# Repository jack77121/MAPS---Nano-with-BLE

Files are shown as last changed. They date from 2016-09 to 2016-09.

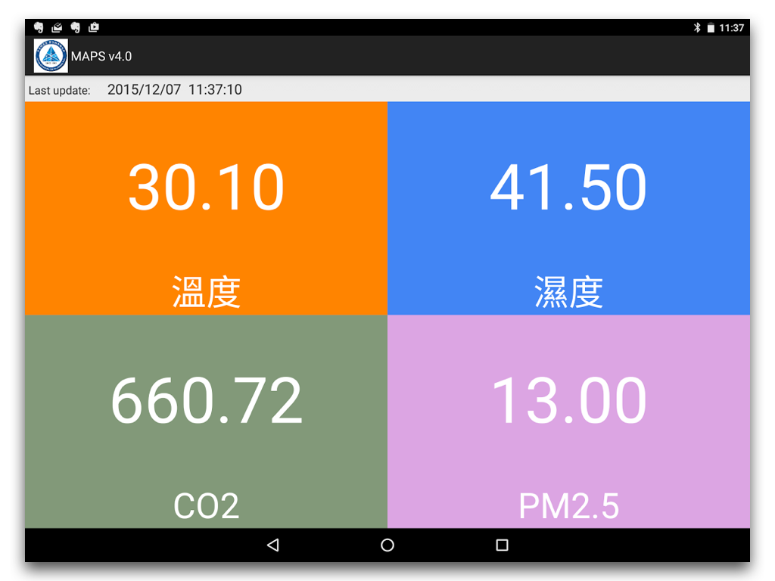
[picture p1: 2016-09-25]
app_figure.png

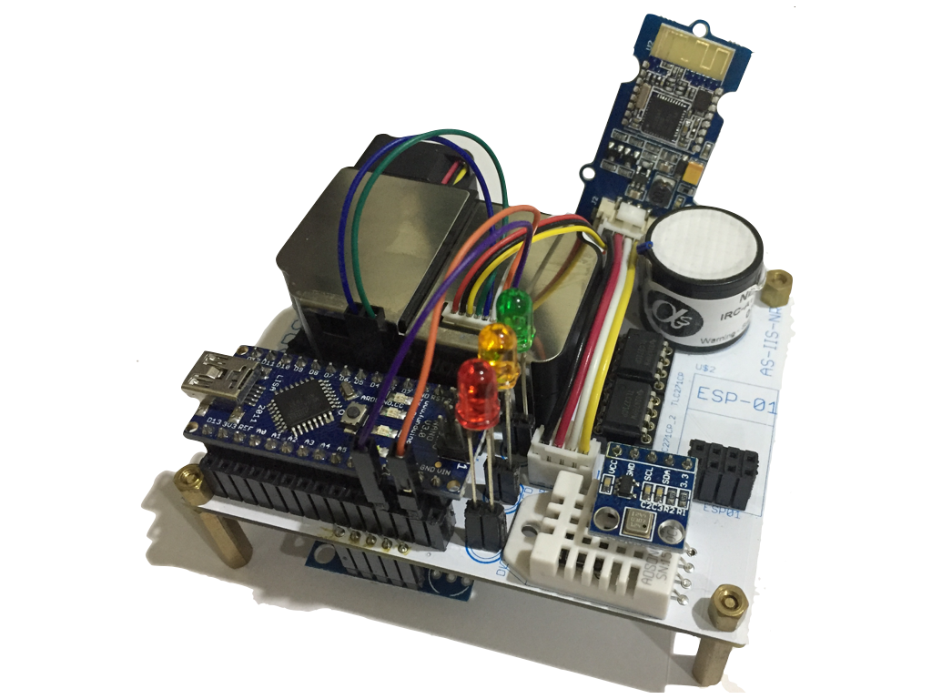
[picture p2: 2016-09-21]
MAPS_BLE_appearance.png

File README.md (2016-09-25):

# MAPS-Arduino Nano
![Image of PCB layout]
(https://github.com/jack77121/MAPS---Nano-with-BLE/blob/master/MAPS_BLE_appearance.png)

## Story
**M**icro **A**ir **P**ollution **S**ensing - MAPS

Air pollution is a hot topic in recent years, especially - **Particulate Matter**. Traditional sensing method, we can only depend on professional sensors/devices, with large volume, heave weight and insanity price.
Thanks to the technology, now we could build our own air pollution sensing station, with micro volume, light weight and the price is affordable :). With MAPS, you can sense air pollution any where, any time by yourself, you can also give it a battery module to increase its mobility!

For more air pollution sensing project, you can visit [LASS facebook](https://www.facebook.com/groups/1607718702812067/) and [LASS github](https://github.com/LinkItONEDevGroup/LASS), we are makers who sense anything in our environment!

## Hardware & Sensors
Module      |	Description
------------|--------------
Arduino Nano|Mainboard
RTC         |time sync
BLE         |pair with smart phone
G3 (pms3003)|Particalute matter (PM)
DHT22       |Temperature & humidity
BMP180      |Ambient pressure
IRC-A1      |CO<sub>2</sub>

## PCB layout & dimensions
![Image of pcb layout]
(https://github.com/jack77121/MAPS---Nano-with-BLE/blob/master/PCB_layout.png)

(unit: mm)

## Installation
1. Upload *MAPS_BLE.ino* to your nano.
2. Compile and install *MAPS_ble* to android phone.
3. Choose to pair the MAPS BLE module from app.
4. You are ready to see the sensors data on you phone.

![Image of app after pairing]
(https://github.com/jack77121/MAPS---Nano-with-BLE/blob/master/app_figure.png)

## Notes
* I use 3 LEDs to show the CO<sub>2</sub> and PM level, whether its safe (green: PM<sub>2.5</sub> <= 32 and CO<sub>2</sub> <= 1000), warning (orange: 32 < PM<sub>2.5</sub> <= 53) and danger (red: PM<sub>2.5</sub> >53 or CO<sub>2</sub> > 1000)
* BLE module use grove universal sockets, can easily replace with your favorite module (maybe a data logger instead), just beware that the socket is connect to **5v power**. 
* ESP-01 socket is preserve for esp8266 module extension, it's fine to leave it if you don't need it.

## Reviews
1. IRC-A1 is a good sensor for CO<sub>2</sub> sensing, but with great power, you also need great skill to use it. You need to add operational amplifier (OPA) in your circuit, infact, most of my circuit and components are for the IRC-A1, include TLC271cp (OPA), IRF520 (MOSFET) and several resistor & capacitor. You also need to calibrate it, with ZERO gas (0 ppm CO<sub>2</sub>) and fix-concentration target gas (for me, 1000 ppm CO<sub>2</sub>).
I think the better circuit should use an external power with low-dropout (LDO) regulator as its power source, and use a crystal oscillator to trigger it (like it mention in its spec, but in this project, I use arduino PWM library to simulate the duty cycle it needs, maybe that's why I cannnot get the best result) .
2. The polygon of GND should not be that large, because it transfers the heat, and it will affect the DHT22 accuracy.

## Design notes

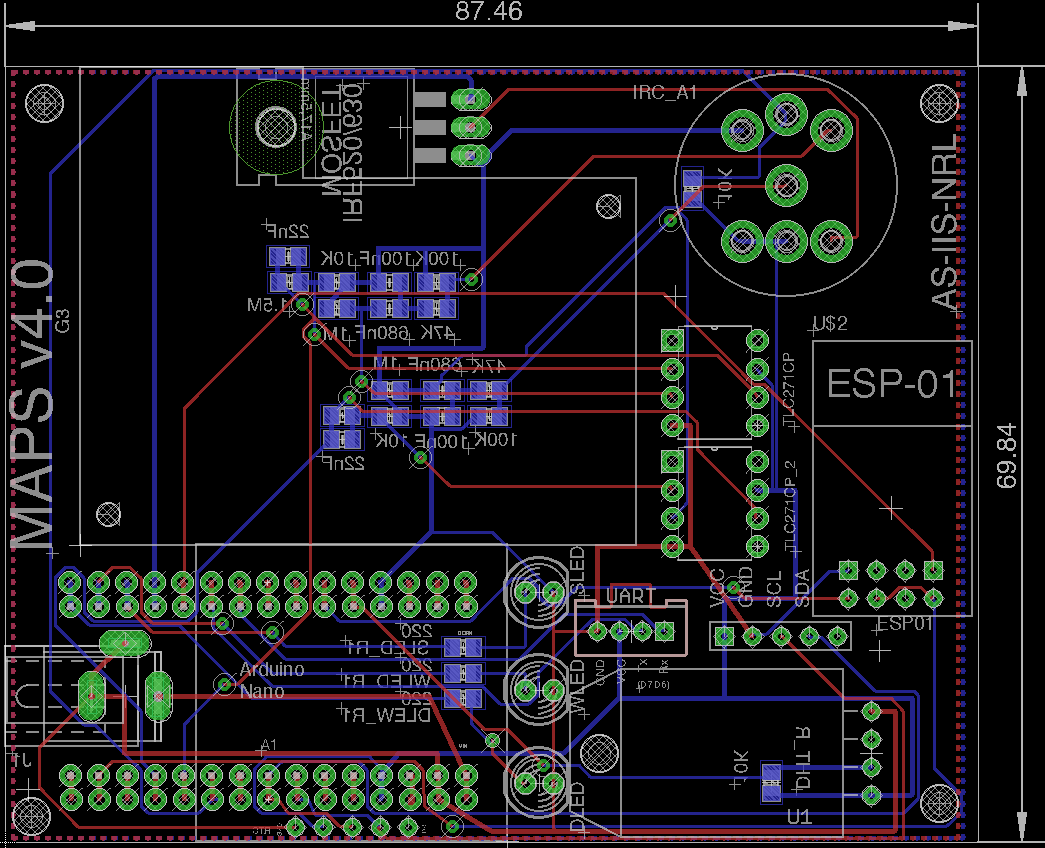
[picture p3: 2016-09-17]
PCB_layout.png

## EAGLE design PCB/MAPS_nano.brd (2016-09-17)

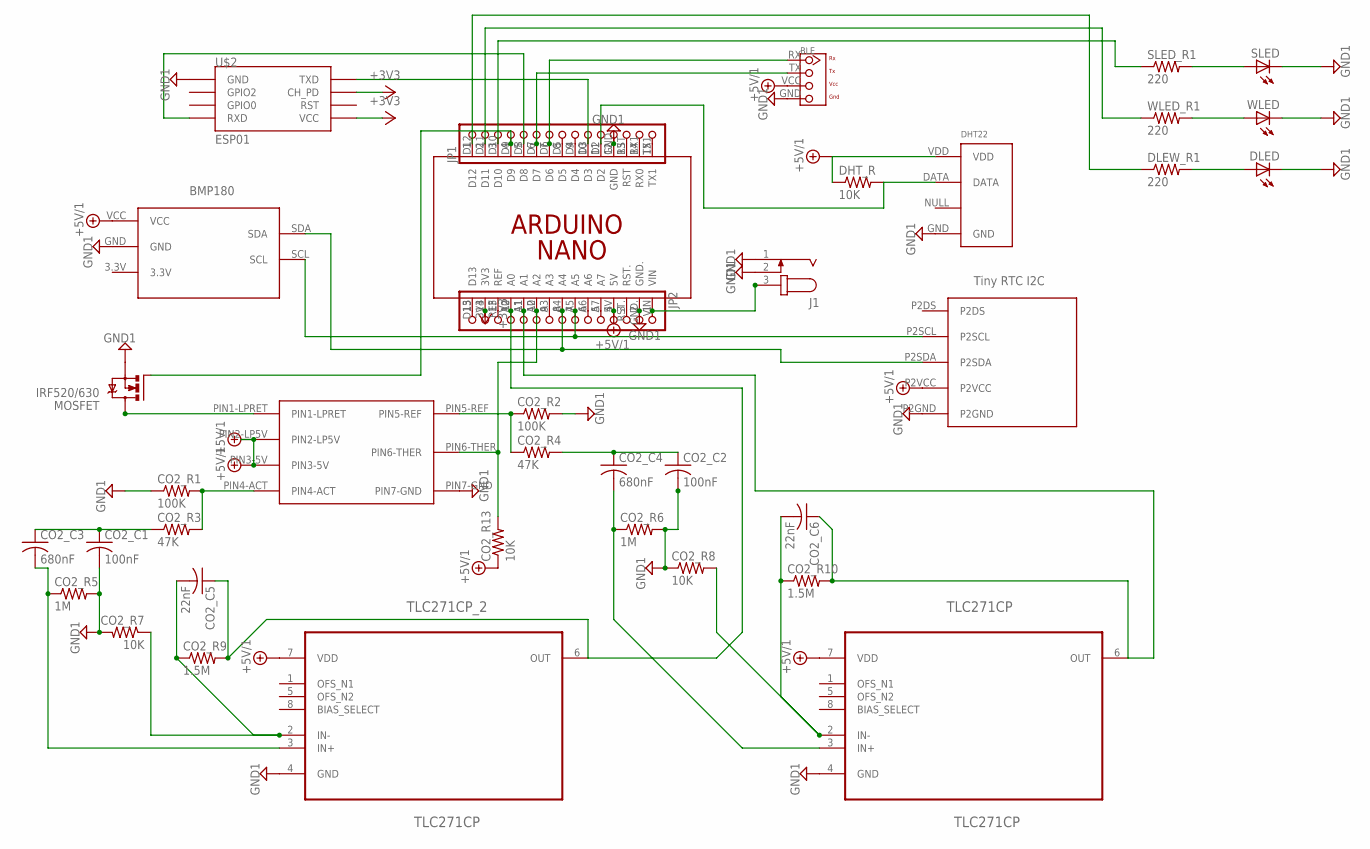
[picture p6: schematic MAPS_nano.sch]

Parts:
BMP180: BMP180
CO2_C1, CO2_C2: 100nF; C0805
CO2_C3, CO2_C4: 680nF; C0805
CO2_C5, CO2_C6: 22nF; C0805
CO2_R1, CO2_R2: 100K; R0805
CO2_R3, CO2_R4: 47K; R0805
CO2_R5, CO2_R6: 1M; R0805
CO2_R7, CO2_R8, CO2_R13: 10K; R0805
CO2_R9, CO2_R10: 1.5M; R0805
DHT_R: 10K; R0805
DLED: LED5MM
DLEW_R1: 220; R0805
J1: JACK-PLUG0; SPC4077
J2: TWIG-4P-2.0-2.0; 4P-2.0
JP1, JP2: PINHD-1X15-CB; 1X15-CB
MOSFET: IRF520/630; TO220BH
PCB1: ARDUINO_NANO
SLED: LED5MM
SLED_R1: 220; R0805
TLC271CP, TLC271CP_2: TLC271CP; DIP254P762X508-8
U1: RHT03_DHT-22_AM2302RA; RHT03_DHT-22/RA
U$1: IRC-A1; ALPHASENSE
U$2: ESP01
U$3: RTC_TINY_IIC
WLED: LED5MM
WLED_R1: 220; R0805

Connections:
+3V3: JP2.14, PCB1.3V3, U$2.CH_PD, U$2.VCC
+5V/1: BMP180.VCC, CO2_R13.1, DHT_R.1, J2.VCC, JP2.4, PCB1.5V, TLC271CP.7 (VDD), TLC271CP_2.7 (VDD), U1.VDD, U$1.PIN2-LP5V, U$1.PIN3-5V, U$3.P2VCC
GND1: BMP180.GND, CO2_C1.2, CO2_C2.2, CO2_R1.1, CO2_R2.2, CO2_R5.2, CO2_R6.2, CO2_R7.2, CO2_R8.1, DLED.K (C), J1.1, J1.2, J2.GND, JP1.12, JP2.2, MOSFET.S, PCB1.GND, PCB1.GND., SLED.K (C), TLC271CP.4 (GND), TLC271CP_2.4 (GND), U1.GND, U$1.PIN7-GND, U$2.GND, U$3.P2GND, WLED.K (C)
unnamed: DHT_R.2, JP1.11, PCB1.D2, U1.DATA
unnamed: J1.3, JP2.1, PCB1.VIN
unnamed: JP1.4, MOSFET.G, PCB1.D9
unnamed: MOSFET.D, U$1.PIN1-LPRET
unnamed: CO2_R13.2, JP2.10, PCB1.A2, U$1.PIN6-THER
unnamed: BMP180.SDA, JP2.8, PCB1.A4, U$3.P2SDA
unnamed: BMP180.SCL, JP2.7, PCB1.A5, U$3.P2SCL
unnamed: CO2_C1.1, CO2_C3.1, CO2_R3.1
unnamed: CO2_R1.2, CO2_R3.2, U$1.PIN4-ACT
unnamed: CO2_C3.2, CO2_R5.1, TLC271CP_2.3 (IN+)
unnamed: CO2_C5.2, CO2_R7.1, CO2_R9.1, TLC271CP_2.2 (IN-)
unnamed: CO2_C5.1, CO2_R9.2, JP2.12, PCB1.A0, TLC271CP_2.6 (OUT)
unnamed: DLEW_R1.1, JP1.1, PCB1.D12
unnamed: CO2_R2.1, CO2_R4.1, U$1.PIN5-REF
unnamed: CO2_C2.1, CO2_C4.1, CO2_R4.2
unnamed: CO2_C4.2, CO2_R6.1, TLC271CP.3 (IN+)
unnamed: JP1.2, PCB1.D11, WLED_R1.1
unnamed: JP1.3, PCB1.D10, SLED_R1.1
unnamed: CO2_C6.2, CO2_R8.2, CO2_R10.1, TLC271CP.2 (IN-)
unnamed: SLED.A, SLED_R1.2
unnamed: JP1.5, PCB1.D8, U$2.RX (RXD)
unnamed: J2.RX, JP1.7, PCB1.D6
unnamed: J2.TX, JP1.6, PCB1.D7
unnamed: CO2_C6.1, CO2_R10.2, JP2.11, PCB1.A1, TLC271CP.6 (OUT)
unnamed: JP1.8, PCB1.D5
unnamed: JP1.9, PCB1.D4
unnamed: JP1.10, PCB1.D3, U$2.TX (TXD)
unnamed: JP1.13, PCB1.RST
unnamed: JP1.14, PCB1.RX1 (RX0)
unnamed: JP1.15, PCB1.TX1
unnamed: JP2.3, PCB1.RST.
unnamed: JP2.5, PCB1.A7
unnamed: JP2.6, PCB1.A6
unnamed: JP2.9, PCB1.A3
unnamed: JP2.13, PCB1.REF
unnamed: JP2.15, PCB1.D13
unnamed: WLED.A, WLED_R1.2
unnamed: DLED.A, DLEW_R1.2

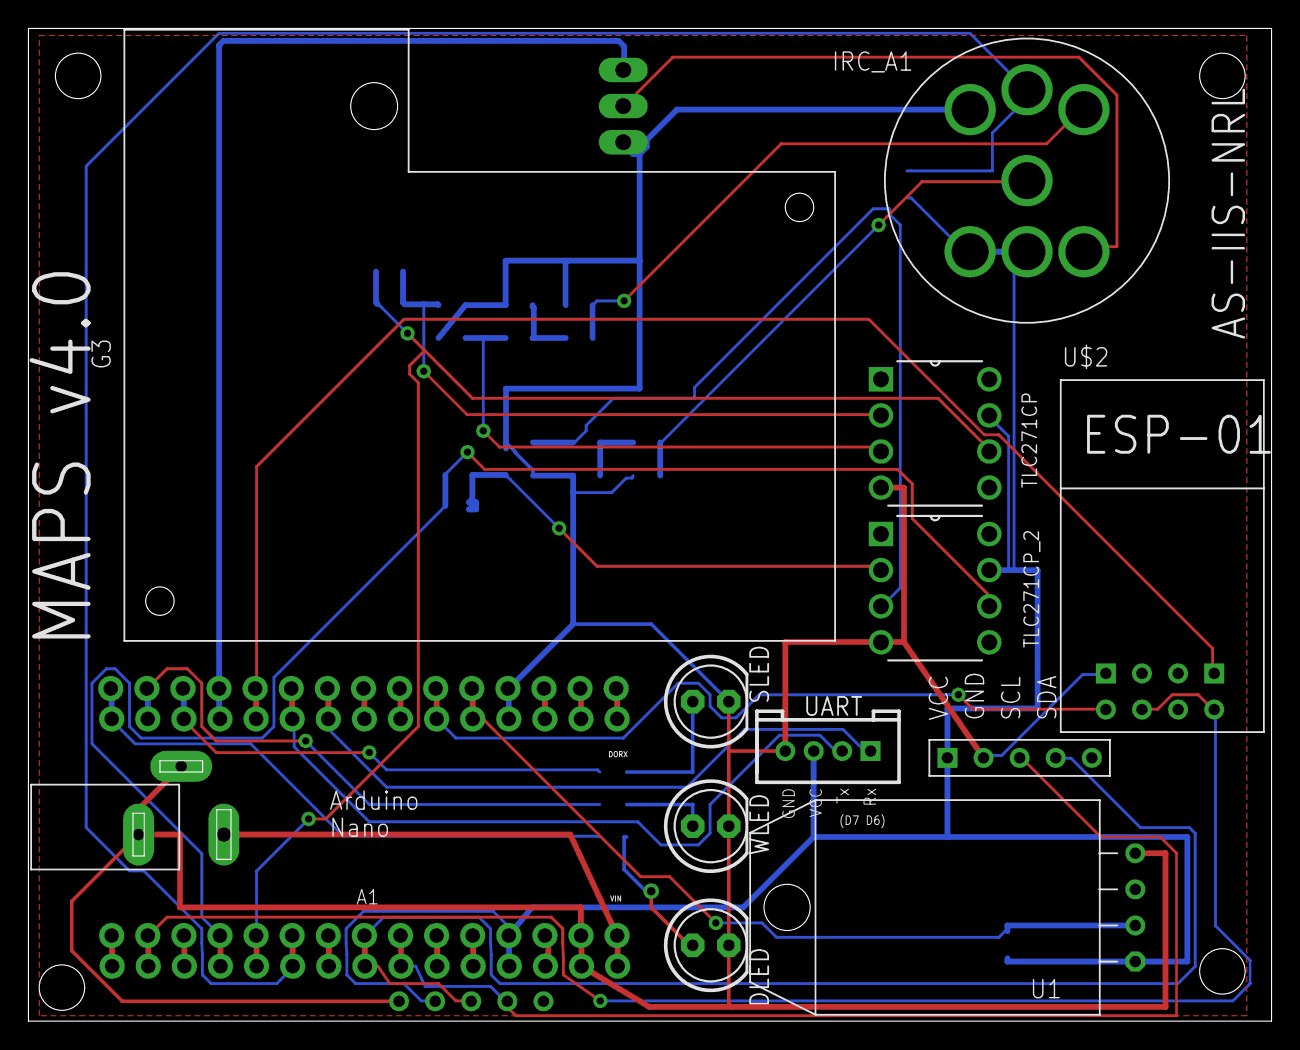
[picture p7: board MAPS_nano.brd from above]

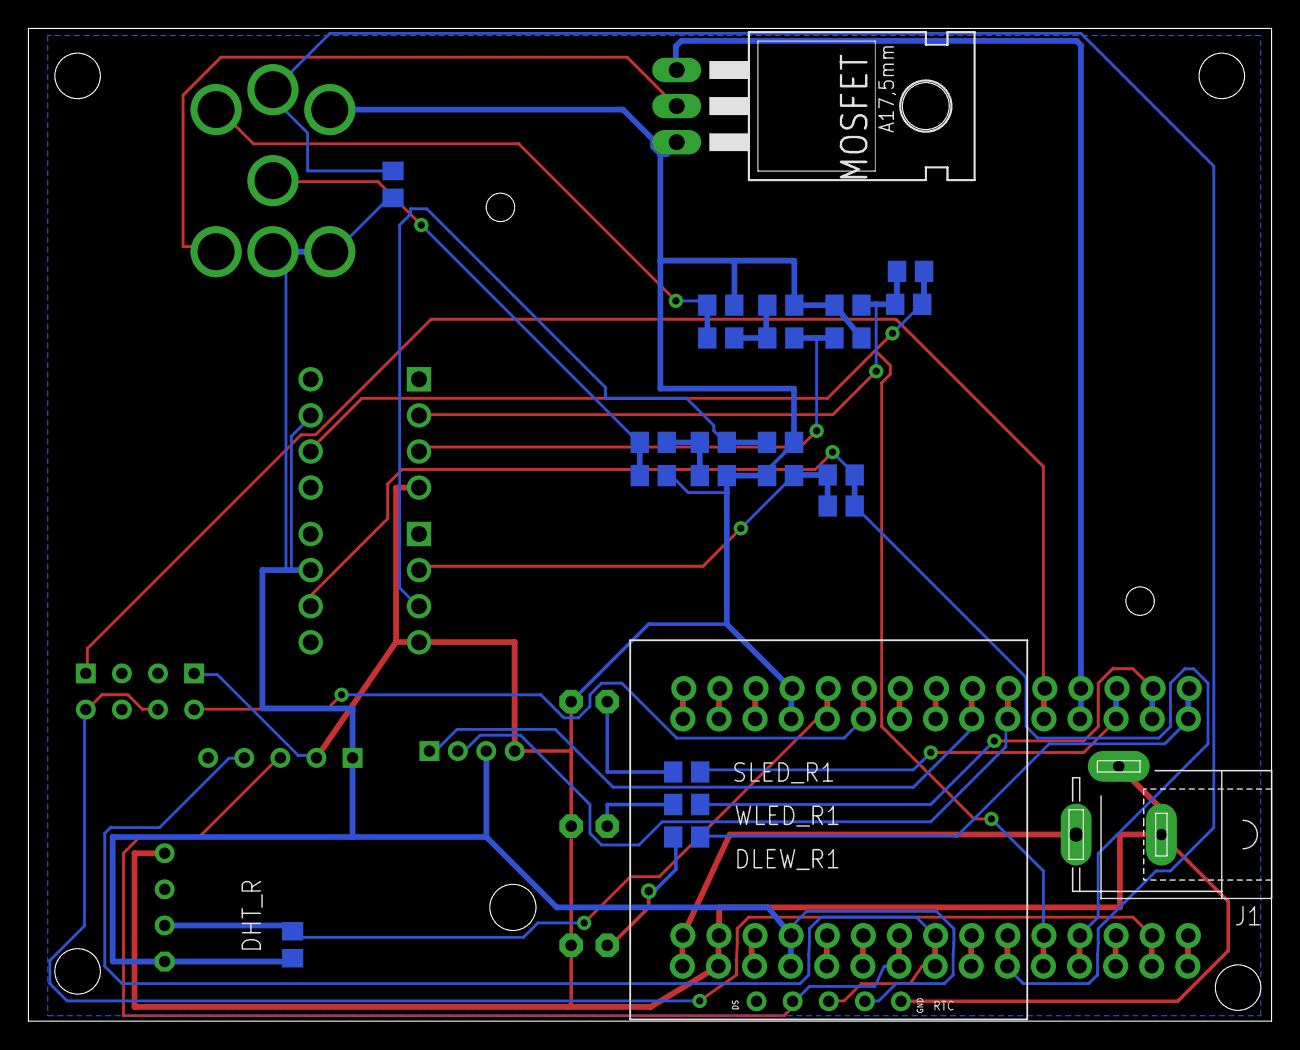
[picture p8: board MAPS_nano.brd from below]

Board: 2 copper layers, 87.5 x 69.8 mm, 38 parts (24 on the bottom side), 41 nets.

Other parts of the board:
U$4: G3

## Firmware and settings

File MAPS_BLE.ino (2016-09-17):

#include <Time.h>            // time library
#include "DHT.h"             // temperature and humidity DHT22 library
#include <Wire.h>            // Wire library
#include <TimerOne.h>        // timerone library, we need this to trigger CO2 sensor
#include <SoftwareSerial.h>  // SoftwareSerial library, we need this for Grove BLE v1.0
#include <SFE_BMP180.h>      // bmp180
#include "RTClib.h"          // tiny rtc i2c module

#define ERROR -999

#define DHTPIN 2              // DHT pin
#define DHTTYPE DHT22         // DHT type
#define RxD 6                 // connect to BLE tx
#define TxD 7                 // connect to BLE rx
#define pmRxD 4               // connect to pm2.5 G3 tx
#define pmTxD 5               // connect to pm2.5 G3 rx

#define source_drive 9        // trigger CO2 sensor
#define CALIBRATE_CONCENTRATION 1000
#define CO2_a 0.0007
#define CO2_b 0.00041
#define CO2_c 0.897
#define CO2_Ba 0.0005
#define CO2_CLB_RATIO 1.269052	//this should be different for every sensors - ACT/REF
#define CO2_ZERO 1.354519		//this should be different for every sensors - ACT0/REF0
#define CO2_Tcal 26.74031		//this should be different for every sensors - calibration temperature

#define MAPS_ID "000"			//device ID

#define SAFE_LIGHT 10  			//led pin #
#define WARN_LIGHT 11			//led pin #
#define DANGER_LIGHT 12			//led pin #

#define PM_SAFE 35				//PM2.5 safe threshold
#define PM_WARN 53				//PM2.5 warning threshold
#define CO2_SAFE 1000			//CO2 safe threshold (indoor)
//
//#define CO2_CLB_RATIO 1.232713
//#define CO2_ZERO 1.385105
//#define CO2_Tcal 26.512873

#define analog_vol 0.0048875  	// 5v/1023

SoftwareSerial BLE(RxD,TxD);  	// for BLE
SoftwareSerial G3(pmRxD,pmTxD);	// for pm2.5 G3 module
/********
for CO2 temperature and Resistor transform, these values are from CO2 spec
********/
const int Z = 0;
const int T = 10;
const int TWT = 20;
const int THT = 30;
const int FT = 40;
const int FFT = 50;
const int ST = 60;

const int Z_R = 8661;
const int T_R = 5541;
const int TWT_R = 3655;
const int THT_R = 2478;
const int FT_R = 1723;
const int FFT_R = 1225;
const int ST_R = 889;



/********
BLE tx string
********/
char buff[150];

/********
DHT 22 sensor
********/
DHT dht(DHTPIN, DHTTYPE);   // get DHT ready
float DHT_temperature = 0;  // set global temperature
float DHT_humidity = 0;     // set global humidity

/********
CO2 sensor
********/
float ratioResult = 0;      // ACT and REF voltage ratio
float CO2_temperatureResult = 0;// CO2 sensor's temperature  

/********
PM2.5 sensors
********/
float pm1_result = 0;
float pm25_result = 0;      // G3 sensor value
float pm10_result = 0;      // G3 sensor value

/********
Barometer BMP180
********/
SFE_BMP180 pressure;        // barometer 
double barometer_value;     // barometer value

/********
get BLE ready
********/
void setupBleConnection()
{
	BLE.begin(9600);        // Set BLE BaudRate to default baud rate 9600
	BLE.print("AT+CLEAR");  // clear all previous setting
	BLE.print("AT+ROLE0");  // set the bluetooth name as a slaver
	BLE.print("AT+SAVE1");  // don't save the connect information
}

/********
RTC
********/
RTC_DS1307 rtc;

/********
CPU tick
********/
unsigned long time_after_booting = 0;

/********
package sent
********/
unsigned long packages_num = 0;

/********
onboard led
********/
int led = 13;

/*
   sssssss   eeeeee  ttttttt  u    u    pppppp
   s         e          t     u    u    p    p
   sssssss   eeeeee     t     u    u    pppppp
         s   e          t     u    u    p
   sssssss   eeeeee     t     uuuuuu    p
*/


void setup(){
	Serial.begin(9600);
	
	// BLE pin, set pin 6 as arduino rx, pin 7 as arduino tx, with Software serial library, and start BLE
	pinMode(RxD, INPUT);
	pinMode(TxD, OUTPUT);
	setupBleConnection(); 
	
	
	// G3 pin, set pin 3 as arduino rx, pin 4 as arduino tx, with Software serial library, and start G3
	pinMode(pmRxD, INPUT);
	pinMode(pmTxD, OUTPUT);
	
	
	
	//for CO2 sensor, setup pwm on pin 9, 50% duty cycle
	pinMode(source_drive, OUTPUT);
	Timer1.initialize(1000000); 
	Timer1.pwm(9, 512, 400000);
	
	
	// DHT temperature and humidity
	dht.begin();
	
	
	// Barometer bmp180, uncomment this line, if you want to use it
	//  pressure.begin();
	
	// Check rtc, and set the time if it is not running
	if (! rtc.begin()) {
		Serial.println("Couldn't find RTC");
		while (1);
	}
	//  rtc.adjust(DateTime(F(__DATE__), F(__TIME__)));
	if (! rtc.isrunning()) {
		Serial.println("RTC is NOT running!");
		// Following line sets the RTC to the date & time this sketch was compiled
		rtc.adjust(DateTime(F(__DATE__), F(__TIME__)));
	}
	
	// set led
	pinMode(SAFE_LIGHT, OUTPUT);
	digitalWrite(SAFE_LIGHT, HIGH);
	pinMode(WARN_LIGHT, OUTPUT);
	digitalWrite(WARN_LIGHT, HIGH);
	pinMode(DANGER_LIGHT, OUTPUT);
	digitalWrite(DANGER_LIGHT, HIGH);
	
	// set onboard led
	pinMode(led, OUTPUT); 
	digitalWrite(led, LOW);
}


/*
   L         OOOOOO   OOOOOO   pppppp
   L         O    O   O    O   p    p
   L         O    O   O    O   pppppp
   L         O    O   O    O   p
   LLLLLLL   OOOOOO   OOOOOO   p
*/
void loop(){
	// buffer for data value write through BLE
	char DHT_temp_buff[20];     // temperature value buffer
	char DHT_humidity_buff[20]; // humidity value buffer
	char pm_buff[20];           // pm2.5 value buffer
	char pressure[20];          // barometer value buffer
	char CO2_buff[20];
	
	double ABSx = 0;			// initial value
	double SPANcal = 0;			// initial value
	double ABS = 0;				// initial value
	double ABSt = 0;			// initial value
	double SPANt = 0;			// initial value
	double CO2_ppm = 0;			// initial value
	 
	// get CPU tick (second)
	time_after_booting = millis()/1000;
	
	// get time
	DateTime maps_time = rtc.now();
	
	// Reading alpha sense CO2 voltage, parameter: sensing time in millisecond, change it whenever you want
	ReadVoltage(57000);
	
	
	//try to get the concentration in ppm
	ABSx = Absorbance(CO2_CLB_RATIO, CO2_ZERO);
	SPANcal = Span(ABSx, CO2_b, CALIBRATE_CONCENTRATION, CO2_c);
	ABS = Absorbance(ratioResult, CO2_ZERO);
	ABSt = AbsorbanceCompensation(ABS, CO2_a, CO2_temperatureResult, CO2_Tcal);
	SPANt = SpanCompensation(SPANcal, CO2_Ba, CO2_temperatureResult, CO2_Tcal);
	CO2_ppm = GasConcentration(ABSt, SPANt, CO2_b, CO2_c, CO2_temperatureResult, CO2_Tcal);
	
	Serial.print("T+");
	Serial.print(maps_time.year(), DEC);
	Serial.print('+');
	Serial.print(maps_time.month(), DEC);
	Serial.print('+');
	Serial.print(maps_time.day(), DEC);
	Serial.print("+");
	Serial.print(maps_time.hour(), DEC);
	Serial.print('+');
	Serial.print(maps_time.minute(), DEC);
	Serial.print('+');
	Serial.print(maps_time.second(), DEC);
	Serial.print('+');
	Serial.print("C+");
	Serial.print(ratioResult, 6);
	Serial.print("+");
	Serial.print(CO2_temperatureResult, 6);
	Serial.print("+");
	Serial.print(CO2_ppm);
	Serial.print("+");
	
	// read temperature and humidity from DHT
	TmpHmd();
	Serial.print("D+");
	Serial.print(DHT_temperature);
	Serial.print("+");
	Serial.print(DHT_humidity);
	Serial.print("+");
	
	// PM2.5 
	pm25sensorG3(pm1_result, pm25_result, pm10_result);
	Serial.print("P+");
	Serial.print(pm1_result);	//PM1
	Serial.print("+");
	Serial.print(pm25_result);	//PM2.5
	Serial.print("+");
	Serial.print(pm10_result);	//PM10
	Serial.print("+");
	
	// get barometer pressure value
	barometer_value = -1; // getPressure();
	Serial.print("B+");
	Serial.print(barometer_value);
	Serial.print("+");
	
	// get CPU tick
	Serial.print("U+");
	Serial.print(time_after_booting);
	Serial.print("+");
	
	// get package sequence
	Serial.print("K+");
	Serial.print(packages_num);
	packages_num+=1;
	Serial.print("+");
	
	// get MAPS ID
	Serial.print("I+");
	Serial.print(MAPS_ID);
	
	
	// get float value to string, and send by BLE, sprintf is not support for %f on Arduino due to some performance issue (from google XD)
	BLE.listen();
	dtostrf(DHT_temperature, 2, 2, DHT_temp_buff);
	dtostrf(DHT_humidity, 2, 2, DHT_humidity_buff);
	dtostrf(pm25_result, 2, 2, pm_buff);
	dtostrf(CO2_ppm, 2, 2, CO2_buff);
	
	sprintf(buff, "tmp,%s", DHT_temp_buff);
	BLE.print(buff);
	delay(250);
	
	sprintf(buff, "hmd,%s", DHT_humidity_buff);
	BLE.print(buff);
	delay(250);
	
	sprintf(buff, "pm25,%s", pm_buff);
	BLE.print(buff);
	delay(250);
	
	sprintf(buff, "co2,%s", CO2_buff);
	BLE.print(buff);
	
	// set led light state
	if(pm25_result <= PM_SAFE && CO2_ppm <= CO2_SAFE){  //both value are in safe state, green light
		digitalWrite(SAFE_LIGHT, HIGH);
		digitalWrite(WARN_LIGHT, LOW);
		digitalWrite(DANGER_LIGHT, LOW);
	}
	else if(pm25_result > PM_SAFE && pm25_result <= PM_WARN){  // pm2.5 are in the warning state, yellow light
		digitalWrite(SAFE_LIGHT, LOW);
		digitalWrite(WARN_LIGHT, HIGH);
		digitalWrite(DANGER_LIGHT, LOW);
	}
	else if(pm25_result > PM_WARN || CO2_ppm > CO2_SAFE){  // one of the value is over the limit, red light
		digitalWrite(SAFE_LIGHT, LOW);
		digitalWrite(WARN_LIGHT, LOW);
		digitalWrite(DANGER_LIGHT, HIGH);
	}
	else{
		// keep the same state
	}
}



/********
CO2 sensor's temperature, use Linear interpolation method
high = high temperature, low = low temperature, high_R = resistance value @ high, low_R = resistance value @ low, R2 = current resistance value
input: high, low temperature & resistance value and current resistance value
output: CO2 sensor's temperature
********/
float CO2_Temperature(float high, float low, float high_R, float low_R, float R2){
	float temperature = 0;
	temperature = (((high * R2) + (high_R * low) - (low * R2) - (high * low_R)) / (high_R - low_R));
	return temperature;
}

/********
CO2 sensor's temperature, need to read CO2 spec, use thermal resistance
input: current resistance value
output: CO2 sensor temperature
********/
float Resis2Temp(float R2){
	float temperature = 0;
	if(R2 <= Z_R && R2 > T_R){
	temperature = CO2_Temperature(T, Z, T_R, Z_R, R2); 
	}
	else if(R2 <= T_R && R2 > TWT_R){
	temperature = CO2_Temperature(TWT, T, TWT_R, T_R, R2);
	}
	else if(R2 <= TWT_R && R2 > THT_R){
	temperature = CO2_Temperature(THT, TWT, THT_R, TWT_R, R2);
	}
	else if(R2 <= THT_R && R2 > FT_R){
	temperature = CO2_Temperature(FT, THT, FT_R, THT_R, R2);
	}
	else if(R2 <= FT_R && R2 > FFT_R){
	temperature = CO2_Temperature(FFT, FT, FFT_R, FT_R, R2);
	}
	else if(R2 <= FFT_R && R2 > ST_R){
	temperature = CO2_Temperature(ST, FFT, ST_R, FFT_R, R2);
	}
	else{
	temperature = ERROR; //error :(
	}
	return temperature;
  
}
         


/********
CO2 sensor's voltage reading
we read Active, Reference voltage and resistance value
input: sensing time in millisecond
output: 
********/
void ReadVoltage(unsigned int sensingSecond){

	float tempActVol = 0;
	float tempRefVol = 0;
	float tempResisVol = 0;
	
	float sumRatioVol = 0;
	float sumResisVol = 0;
	
	float currentMaxActVol = 0;
	float currentMaxRefVol = 0;
	
	
	float ratioNum = 0;
	float resNum = 0;
	
	
	unsigned long now;
	unsigned long startTime = millis();
	
	
	//Read voltage for 'sensingSecond'
	while(1){
		now = millis();
		tempActVol = analogRead(A0);  // Act
		tempRefVol = analogRead(A1);  // Ref
		tempResisVol = analogRead(A2);// Resistance
		
		// to measure the current resistance for CO2 sensor it self, I learn from these place: 
		// http://forum.arduino.cc/index.php/topic,+21614.0.html
		// https://en.wikipedia.org/wiki/Voltage_divider
		// for R1, I use 10k Ohm, and Vin 5V
		tempResisVol = tempResisVol * analog_vol;
		sumResisVol += Resis2Temp(((10.0/((5.0 / tempResisVol)-1.0))*1000.0));
		resNum += 1;
		/*
		   CO2 voltage (both Act and Ref) is a wave, ex:
		   0, 0.45, 0.9, localMax, 1.0, 0.5, 0,.....,0, 0.43, 0.79, localMax, 1.1, 0.7, 0,......
		   we only need the localMax value, the code below is doing this job, I use Act voltage as the main target
		*/
		if(tempActVol > currentMaxActVol){
			currentMaxActVol = tempActVol;
			currentMaxRefVol = tempRefVol;
		}
		else if(tempActVol == 0 && currentMaxActVol != 0 && currentMaxRefVol != 0){
			sumRatioVol += (currentMaxActVol/currentMaxRefVol);
			ratioNum += 1;
			currentMaxActVol = 0;
			currentMaxRefVol = 0;
		}
		else{
			//nothing
		}
		if(now - startTime >= sensingSecond){
			break;
		}
	}  
	
	if(ratioNum > 0){
		ratioResult = sumRatioVol/ratioNum;
	}
	else{
		ratioResult = ERROR;
	}
	if(resNum > 0){
		CO2_temperatureResult = sumResisVol/resNum;
	}
	else{
		CO2_temperatureResult = ERROR;
	}

  

}      


/********
CO2 concentration (ppm) converter
********/ 
double Span(double ABSx, double b, double x, double c){
	double SPAN;
	double temp_denominator;
	double temp_xc;
	temp_xc = pow(x,c);
	temp_denominator = (1-exp(-(b * temp_xc)));
	SPAN = (ABSx/temp_denominator);
	return SPAN;
}
double Absorbance(double RATIO, double ZERO){
    double ABS;
    ABS = (1 - (RATIO/ZERO));
    return ABS;
}
double AbsorbanceCompensation(double ABS, double a, double T, double Tcal){
    double ABSt;
    ABSt = (1 - ((1 - ABS) * (1 + a * (T - Tcal))));
    return ABSt;
}
double SpanCompensation(double SPANcal, double Ba, double T, double Tcal){
    double SPANt;
    SPANt = (SPANcal + (Ba * (T - Tcal)));
    return SPANt;
}
double GasConcentration(double ABSt, double SPANt, double b, double c, double T, double Tcal){
    double temperature_para;
    double numerator;
    double denominator;
    double base;
    double main_para;
    double pow_num;
    double ppm;

    temperature_para = (T / Tcal);
    numerator = log( (1-(ABSt / SPANt)) );
    denominator = 0-b;
    base = (numerator / denominator);
    pow_num = (1 / c);
    main_para = pow(base, pow_num);
    ppm = temperature_para * main_para;
    return ppm;
}





/*==========Temperature and Humidity sensor function==========*/
void TmpHmd(){
	DHT_temperature = dht.readTemperature();
	DHT_humidity = dht.readHumidity();
}

/*==========PM2.5 function==========*/
void pm25sensorG3(float &pm1, float &pm25, float &pm10){
	int count=0;
	float pm25result = 0;
	byte incomeByte[24];
	boolean startcount=false;
	byte data;
	G3.begin(9600);
	while (1){
		if(G3.available()){
			data=G3.read();
			if(data==0x42 && !startcount){
		    	startcount = true;
		    	incomeByte[count]=data;
		    	count++;
		  	}
			else if(startcount){
				incomeByte[count]=data;
			    count++;
			    if(count>=24){
					break;
				}
			}
		}
	}
	G3.end();
	G3.flush();
	unsigned int calcsum = 0;
	unsigned int exptsum;
	// reference https://github.com/avaldebe/AQmon/blob/master/Documents/PMS3003_LOGOELE.pdf
	for(int i = 0; i < 22; i++) {
		calcsum += (unsigned int)incomeByte[i];
	}
	exptsum = ((unsigned int)incomeByte[22] << 8) + (unsigned int)incomeByte[23];
	if(calcsum == exptsum){
		pm1 = ((unsigned int)incomeByte[10] << 8) + (unsigned int)incomeByte[11];
		pm25 = ((unsigned int)incomeByte[12] << 8) + (unsigned int)incomeByte[13];
		pm10 = ((unsigned int)incomeByte[14] << 8) + (unsigned int)incomeByte[15];
	} 
	else{
	//    Serial.println("#[exception] PM2.5 Sensor CHECKSUM ERROR!");
	}     
}

/*==========BMP180 Atmosphere pressure function==========*/
double getPressure()
{
  char status;
  double T,P,p0,a;

  // You must first get a temperature measurement to perform a pressure reading.
  // Start a temperature measurement:
  // If request is successful, the number of ms to wait is returned.
  // If request is unsuccessful, 0 is returned.

  status = pressure.startTemperature();
	if (status != 0){
	// Wait for the measurement to complete:
	
	delay(status);
	
	// Retrieve the completed temperature measurement:
	// Note that the measurement is stored in the variable T.
	// Use '&T' to provide the address of T to the function.
	// Function returns 1 if successful, 0 if failure.
	
	status = pressure.getTemperature(T);
		if (status != 0){
			// Start a pressure measurement:
			// The parameter is the oversampling setting, from 0 to 3 (highest res, longest wait).
			// If request is successful, the number of ms to wait is returned.
			// If request is unsuccessful, 0 is returned.
			
			status = pressure.startPressure(3);
			if (status != 0){
				// Wait for the measurement to complete:
				delay(status);
				
				// Retrieve the completed pressure measurement:
				// Note that the measurement is stored in the variable P.
				// Use '&P' to provide the address of P.
				// Note also that the function requires the previous temperature measurement (T).
				// (If temperature is stable, you can do one temperature measurement for a number of pressure measurements.)
				// Function returns 1 if successful, 0 if failure.
				
				status = pressure.getPressure(P,T);
				if (status != 0){
					return(P);
				}
				else{
					// Serial.println("error retrieving pressure measurement\n");
				} 
			}
			else{
				// Serial.println("error starting pressure measurement\n");
			} 
		}
		else{
			// Serial.println("error retrieving temperature measurement\n");
		}
	}
	else{
		// Serial.println("error starting temperature measurement\n");
	}
}

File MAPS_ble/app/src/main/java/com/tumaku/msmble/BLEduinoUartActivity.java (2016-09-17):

/* Created by Javier Montaner  (twitter: @tumaku_) during M-week (February 2014) of MakeSpaceMadrid
 * http://www.makespacemadrid.org
 * @ 2014 Javier Montaner
 * 
 * Licensed under the MIT Open Source License 
 * http://opensource.org/licenses/MIT
 * 
 * Many thanks to Yeelight (special mention to Daping Liu) and Double Encore (Dave Smith)
 * for their support and shared knowlegde
 * 
 * Based on the API released by Yeelight:
 * http://www.yeelight.com/en_US/info/download
 * 
 * Based on the code created by Dave Smith (Double Encore):
 * https://github.com/devunwired/accessory-samples/tree/master/BluetoothGatt
 * http://www.doubleencore.com/2013/12/bluetooth-smart-for-android/
 * 
 * 
 * Scan Bluetooth Low Energy devices and their services and characteristics.
 * If the Yeelight Service is found, an activity can be launched to control colour and intensity of Yeelight Blue bulb
 * 
 * Tested on a Nexus 7 (2013)
 * 
 */
package com.tumaku.msmble;

import java.util.ArrayList;
import java.util.List;

import android.app.Activity;
import android.content.BroadcastReceiver;
import android.content.Context;
import android.content.Intent;
import android.content.IntentFilter;
import android.os.Bundle;
import android.util.Log;
import android.view.View;
import android.view.View.OnClickListener;
import android.widget.ArrayAdapter;
import android.widget.Button;
import android.widget.CheckBox;
import android.widget.EditText;
import android.widget.Spinner;
import android.widget.TextView;
import android.widget.Toast;

public class BLEduinoUartActivity extends Activity {
	
	/* SensorTag BLE procedure:
	 * The sensors in SensorTag require a special mechanism to use them.
	 * In order to save battery power, every sensor needs to be enabled (i.e. activated) prior 
	 * to reading it or subscribing to notifications on value changes.
	 * This is done by writing a byte into a characteristic present in every service (*_CONF)
	 * Once the sensor is enabled, standard BLE mechanisms apply:
	 * - you can read its value
	 * - you can (un)subscribe to notifications  writing the *-DATA characteristic descriptor 
	 * 
	 * A special case is the Key service that controls the two buttons on sensor tag. This service 
	 * does not require to be enabled. To interact with this service, only the notification mechanism 
	 * applies (read value is not supported - to be confirmed)
	 */
			

	private final static int WSTATE_CONNECT=0;
	private final static int WSTATE_SEARCH_SERVICES=1;
	private final static int WSTATE_NOTIFY_BLEDUINO=2;
	private final static int WSTATE_READ_BLEDUINO=3;
	private final static int WSTATE_DUMMY=4;
	private final static int WSTATE_WRITE_BLEDUINO=5;
	

	private TextView mTextReceived;
	private TextView mTextLongReceived;
	private EditText mTextSent;
	private TextView mTextInfo;
	private TextView mTextNotification;
	private Button mButtonRead;
	private Button mButtonSend;
	private Button mButtonReset;

	private Context mContext;
	private HM10BroadcastReceiver mBroadcastReceiver;
	private String mDeviceAddress;
	private int mState=0;
	
	private TumakuBLE  mTumakuBLE=null;
	
    
	@Override
    public void onCreate(Bundle savedInstanceState) {
        super.onCreate(savedInstanceState);
        setContentView(R.layout.hm10);           
        mContext=this;
        mBroadcastReceiver= new HM10BroadcastReceiver();
        mDeviceAddress=getIntent().getStringExtra(TumakuBLE.EXTRA_ADDRESS);
        if (mDeviceAddress==null) {
            if (Constant.DEBUG) Log.i("JMG","No device address received to start SensorTag Activity");
        	finish();
        }
		mTumakuBLE=((TumakuBLEApplication)getApplication()).getTumakuBLEInstance(this);
        mTumakuBLE.setDeviceAddress(mDeviceAddress);
//        mTextReceived = (TextView) findViewById(R.id.receivedText);
//        mTextLongReceived= (TextView) findViewById(R.id.longReceivedText);
//        mTextSent = (EditText) findViewById(R.id.sentText);
        mTextInfo = (TextView) findViewById(R.id.textInfo);
        mTextNotification = (TextView) findViewById(R.id.textNotification);
//        mButtonRead= (Button) findViewById(R.id.buttonRead);
//        mButtonSend= (Button) findViewById(R.id.buttonSend);
        mButtonReset= (Button) findViewById(R.id.buttonReset);

        
        mButtonRead.setOnClickListener(new View.OnClickListener() {
            public void onClick(View v) {
        	    if ((mState==WSTATE_DUMMY)) {
	        	    mState=WSTATE_READ_BLEDUINO;
	        	    nextState();  
        	    }
            }
        });
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

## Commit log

2016-09-17 update README pcb layout figure
2016-09-17 android app, using Android Studio, edit from hm10 android sample code
